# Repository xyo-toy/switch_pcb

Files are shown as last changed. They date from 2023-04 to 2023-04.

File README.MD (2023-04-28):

# Information
From the following datasheet :
http://ww1.microchip.com/downloads/en/devicedoc/atmel-7766-8-bit-avr-atmega16u4-32u4_datasheet.pdf

## Datasheet sections
Crystal information: p30
Usb related info: p256-259
Information about decoupling capacitors and some components values: "Electrical characteristics"
Boot related info : p80, p340
Reset info : p50-54
Decoupling Capacitor : p306, p307

## Components list

-- 1 ATMega32u4 : https://www.digikey.fr/en/products/detail/microchip-technology/ATMEGA32U4-AUR/3440960
-- 1 Crystal: https://www.digikey.com/product-detail/en/epson/FA-238-16.0000MB-C3/SER3686CT-ND/2403459
-- 2 22pF Capacitors: https://www.digikey.com/product-detail/en/kemet/C0805C220J5GACTU/399-1113-1-ND/411388
-- 4 0.1uF Capacitors: https://www.digikey.com/product-detail/en/yageo/CC0805ZRY5V9BB104/311-1361-1-ND/2103145
-- 1 1uF Capacitors: https://www.digikey.com/product-detail/en/yageo/CC0805KKX7R7BB105/311-1365-1-ND/2103149
-- 1 4.7uF Capacitors: https://www.digikey.com/product-detail/en/murata-electronics-north-america/GRM21BR61E475KA12L/490-3335-1-ND/702876
-- 1 10uF Capacitors: https://www.digikey.com/en/products/detail/yageo/CC0805ZKY5V6BB106/2103093
-- 2 22 Ohm Resistors: https://www.digikey.com/product-detail/en/stackpole-electronics-inc/RMCF0805JT22R0/RMCF0805JT22R0CT-ND/1942533
-- 2 10k Ohm Resistors: https://www.digikey.com/product-detail/en/stackpole-electronics-inc/RMCF0805JT10K0/RMCF0805JT10K0CT-ND/1942577
-- 4 Diodes: https://www.digikey.com/product-detail/en/micro-commercial-co/1N4148W-TP/1N4148WTPMSCT-ND/717311
-- 1 Button: https://www.digikey.com/product-detail/en/e-switch/TL3342F160QG-TR/EG2531CT-ND/379004
-- 1 Mini USB Connector: https://www.digikey.com/product-detail/en/hirose-electric-co-ltd/UX60SC-MB-5S8/H11589CT-ND/1949225

## Net informations
https://electronics.stackexchange.com/questions/424912/how-can-i-program-an-atmega32u4-over-usb-with-this-schematic

## Other references
https://github.com/ruiqimao/keyboard-pcb-guide

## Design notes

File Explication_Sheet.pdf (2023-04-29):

# Projet Switch tester

Groupe 4

April 29, 2023

Notre projet consiste `a cr´eer une carte permettant de tester facilement si les switchs d’un clavier fonctionne bien et cette carte se comporte comme un petit clavier `a 4 touches. Tous d’abord, nous utilisons un USB pour alimenter la carte, celle-ci nous permet aussi de programmer l’ATmega au centre de notre carte. Pour faire fonctionner la communication `a travers l’USB, un cristal a ´et´e rajout´e pour avoir une horloge stable d´edi´ee `a ce p´eriph´erique. Pour ´eviter le survoltage du connecteur mini USB, nous avons ajout´e des condensateurs. Dans le cas ou cette entr´ee ne fonctionne pas pour reprogrammer le MCU, nous avons ajout´e un p´eriph´erique SPI pour pouvoir le reprogrammer avec un Arduino en mode ISP. Pour chaque Switch, une diode est li´ee et s’allume quand celui-ci fonctionne. Dans l’´eventualit´e de tests, 3 pins sont mis `a d´ecouvert.

1

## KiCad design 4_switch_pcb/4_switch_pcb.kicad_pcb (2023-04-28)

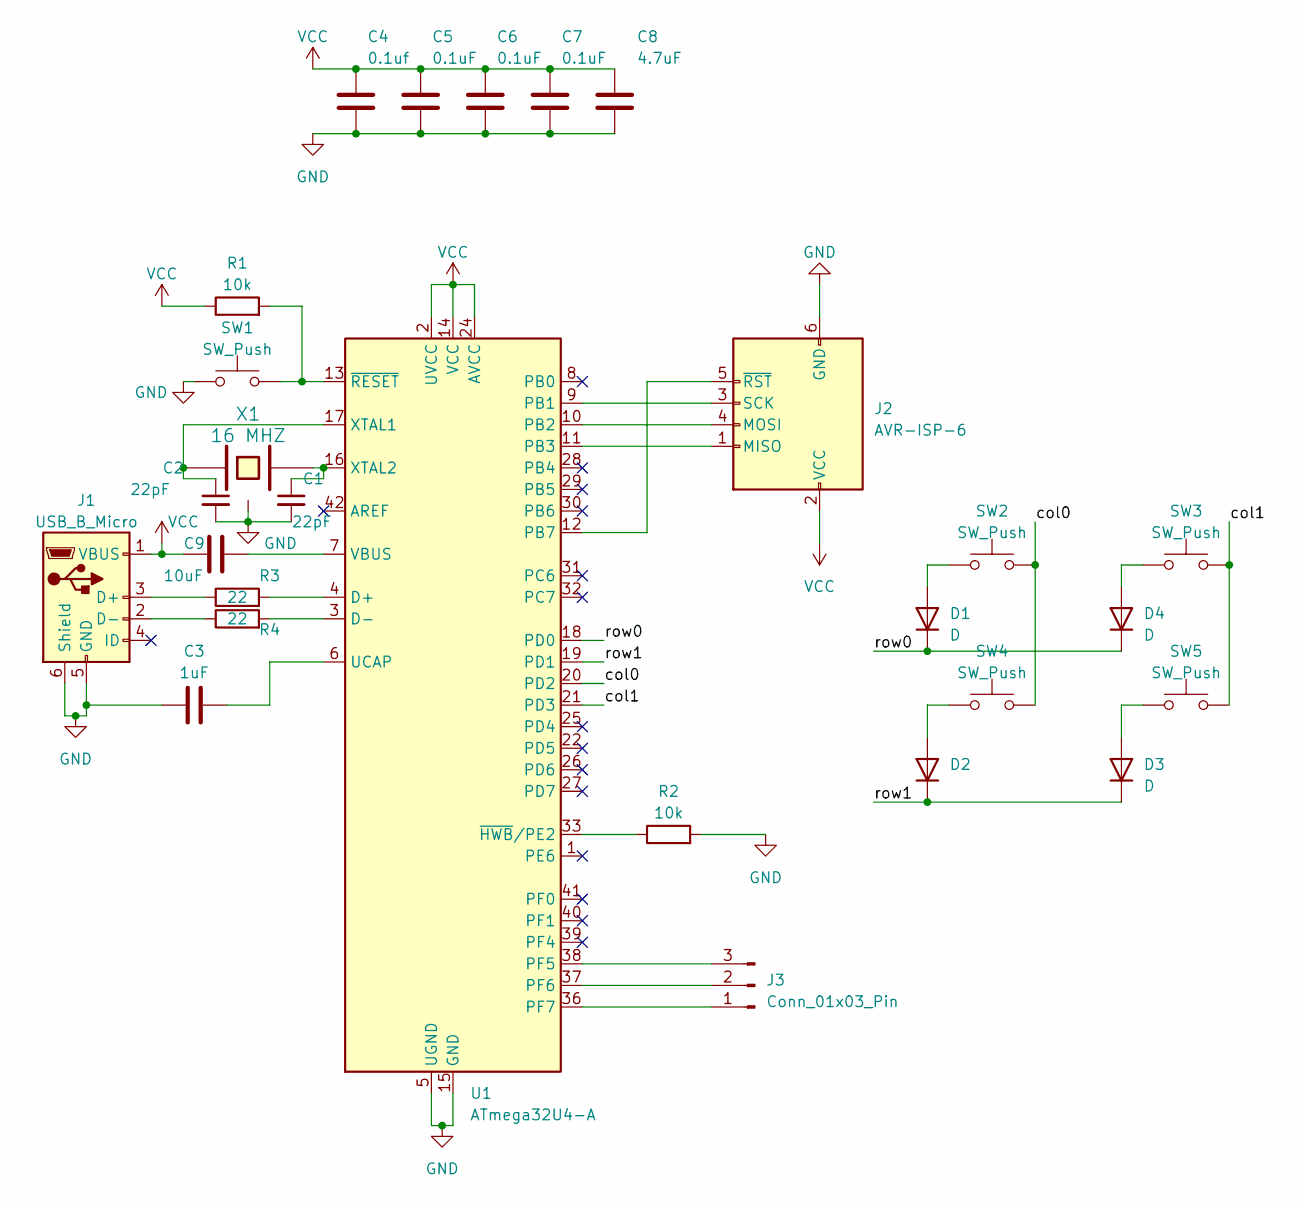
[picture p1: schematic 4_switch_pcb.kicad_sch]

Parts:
C1, C2: 22pF; C_0805_2012Metric_Pad1.18x1.45mm_HandSolder
C3: 1uF; C_0805_2012Metric_Pad1.18x1.45mm_HandSolder
C4: 0.1uf; C_0805_2012Metric_Pad1.18x1.45mm_HandSolder
C5, C6, C7: 0.1uF; C_0805_2012Metric_Pad1.18x1.45mm_HandSolder
C8: 4.7uF; C_0805_2012Metric_Pad1.18x1.45mm_HandSolder
C9: 10uF; C_0805_2012Metric_Pad1.18x1.45mm_HandSolder
D1, D2, D3, D4: D; D_SOD123_axial
J1: USB_B_Micro; USB_miniB_hirose_5S8
J2: AVR-ISP-6
J3: Conn_01x03_Pin; PinHeader_1x03_P1.00mm_Vertical_SMD_Pin1Right
R1, R2: 10k; R_0805_2012Metric_Pad1.20x1.40mm_HandSolder
R3, R4: 22; R_0805_2012Metric_Pad1.20x1.40mm_HandSolder
SW1: SW_Push; SW_SPST_TL3342
SW2, SW3, SW4, SW5: SW_Push; SW_Cherry_MX_1.00u_PCB
U1: ATmega32U4-A; TQFP-44_10x10mm_P0.8mm
X1: 16 MHZ; crystal_FA238-TSX3225

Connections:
/col0: SW2.2, SW4.2, U1.20 (PD2)
/col1: SW3.2, SW5.2, U1.21 (PD3)
/row0: D1.1 (K), D4.1 (K), U1.18 (PD0)
/row1: D2.1 (K), D3.1 (K), U1.19 (PD1)
GND: C1.2, C2.2, C3.1, C4.2, C5.2, C6.2, C7.2, C8.2, J1.5 (GND), J1.6 (Shield), J2.6 (GND), R2.2, SW1.1, U1.5 (UGND), U1.15 (GND), U1.23 (GND), U1.35 (GND), U1.43 (GND), X1.3
unnamed: D1.2 (A), SW2.1
unnamed: D2.2 (A), SW4.1
unnamed: D3.2 (A), SW5.1
unnamed: D4.2 (A), SW3.1
unnamed: J1.3 (D+), R3.1
unnamed: J1.2 (D-), R4.1
unnamed: J2.1 (MISO), U1.11 (PB3)
unnamed: J2.4 (MOSI), U1.10 (PB2)
unnamed: J2.3 (SCK), U1.9 (PB1)
unnamed: J2.5 (~RST), U1.12 (PB7)
unnamed: J3.1, U1.36 (PF7)
unnamed: J3.2, U1.37 (PF6)
unnamed: J3.3, U1.38 (PF5)
unnamed: R3.2, U1.4 (D+)
unnamed: R4.2, U1.3 (D-)
unnamed: C3.2, U1.6 (UCAP)
unnamed: C9.2, U1.7 (VBUS)
unnamed: C2.1, U1.17 (XTAL1), X1.1
unnamed: C1.1, U1.16 (XTAL2), X1.2
unnamed: R2.1, U1.33 (~HWB/PE2)
unnamed: R1.2, SW1.2, U1.13 (~RESET)
VCC: C4.1, C5.1, C6.1, C7.1, C8.1, C9.1, J1.1 (VBUS), J2.2 (VCC), R1.1, U1.2 (UVCC), U1.14 (VCC), U1.24 (AVCC), U1.34 (VCC), U1.44 (AVCC)

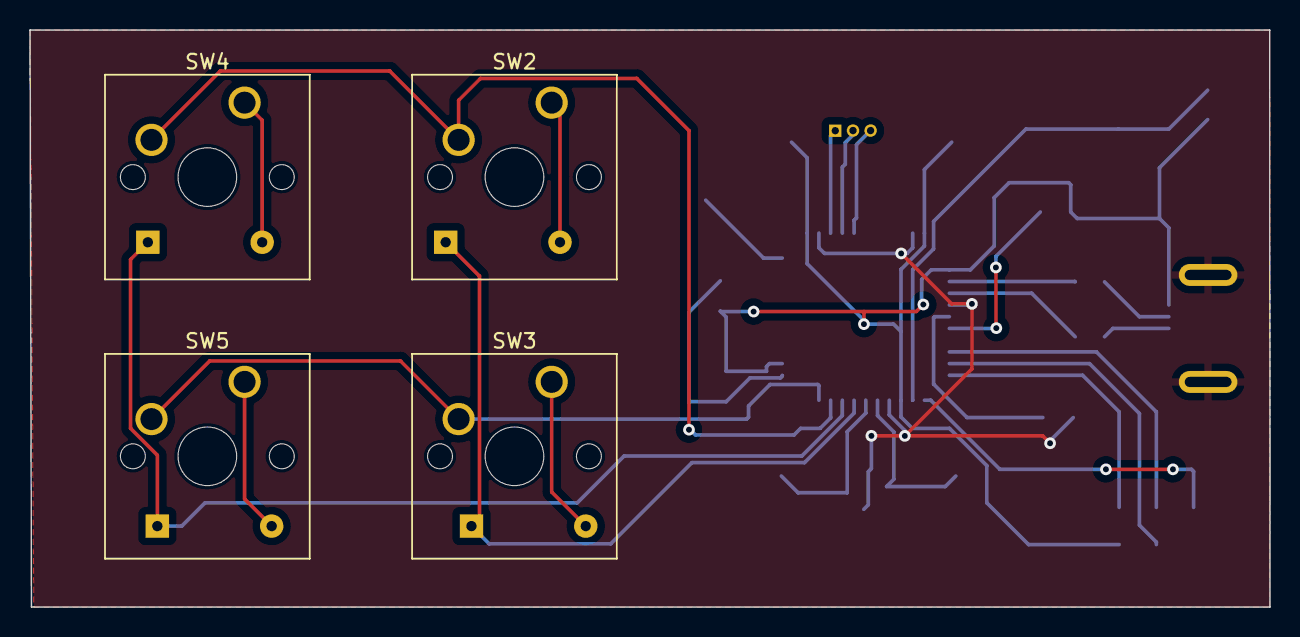
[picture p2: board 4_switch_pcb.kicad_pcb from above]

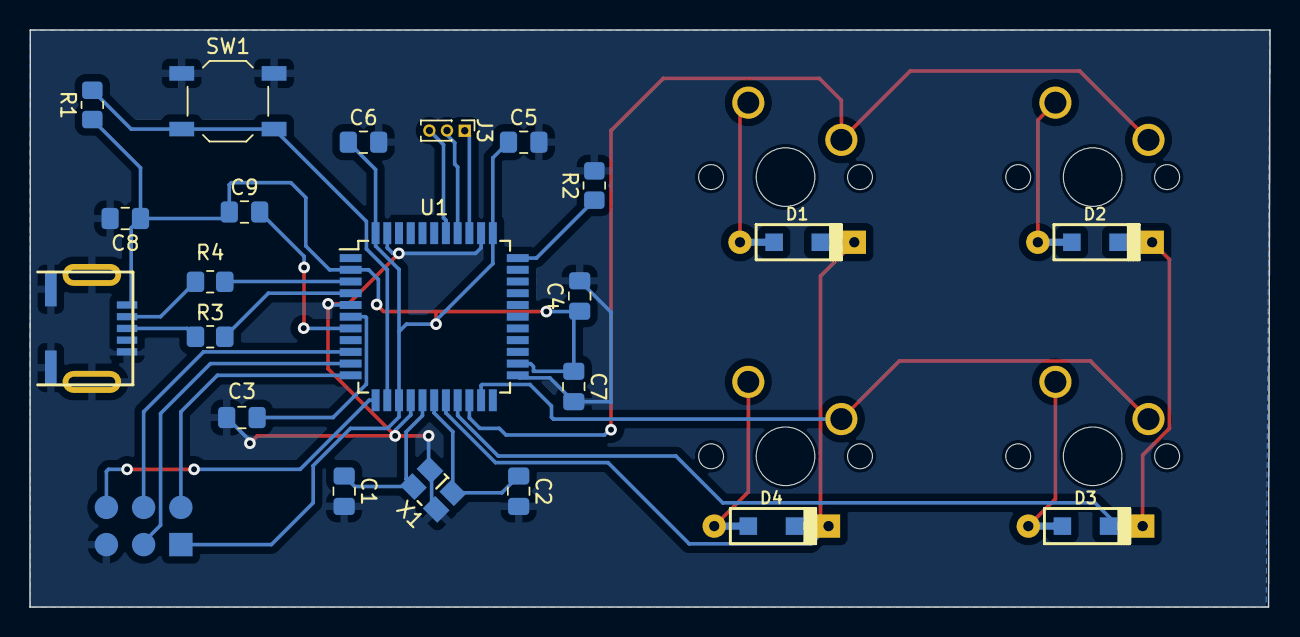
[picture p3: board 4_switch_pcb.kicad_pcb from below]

Board: 2 copper layers, 84.6 x 39.4 mm, 27 parts (23 on the bottom side), 27 nets.

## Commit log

2023-04-07 init repo
    [4_switch_pcb.kicad_pcb, 4_switch_pcb.kicad_sch]
2023-04-16 feat: add switch matrix, isp and header pins
    [4_switch_pcb.kicad_sch]
2023-04-18 feat: add decoupling value, missing vusb capa, crystal frequency
    [4_switch_pcb.kicad_sch]
2023-04-19 feat: add footprints selection
    [4_switch_pcb.kicad_pcb, 4_switch_pcb.kicad_sch]
2023-04-26 component alignement
    [4_switch_pcb.kicad_pcb]
2023-04-28 add base of routing
    [4_switch_pcb.kicad_pcb, 4_switch_pcb.kicad_sch]
2023-04-28 base of pcb edition
    [4_switch_pcb.kicad_pcb]
2023-04-28 pcb finish
    [4_switch_pcb.kicad_pcb, 4_switch_pcb.kicad_sch]
2023-04-28 generate file to send
    [4_switch_pcb-B_Cu.gbr, 4_switch_pcb-B_Mask.gbr, 4_switch_pcb-B_Paste.gbr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]
2023-04-29 add explication sheet and migration BOM to excel
    [4_switch_pcb-B_Cu.gbr, 4_switch_pcb-B_Mask.gbr, 4_switch_pcb-B_Paste.gbr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]
